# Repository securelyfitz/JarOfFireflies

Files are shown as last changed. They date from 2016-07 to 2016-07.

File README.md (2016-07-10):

# Jar of Fireflies
ATtiny-based Jar of Fireflies soldering project with inspiration and reuse from jason webb's https://github.com/jasonwebb/Jar-of-Fireflies

## Hardware Description
This project is intended to be a simple soldering project based on the ATTiny using only a handful of through-hole components. It uses 3 I/O pins to drive 6 charlieplexed LEDs, and an additional 2 I/O pins to control a capacitive sensor.

I originally intended to have the jar's metal ring be touch sensitive alone. However, for cap sensing to work, you need to be grounded, and a PCB inside a glass jar isn't exactly grounded. To account for that, there are several exposed ground pads just inside the ring - touch the ring and one of those pads, and the cap sensing should work.

## Bill of Materials:
* 3x 150 Ohm Resistor
* 2x 1K Ohm Resistor
* 1x 1M Ohm Resistor
* 1x ATTiny85 8-DIP
* 1x 20mm CR2032 holder and battery
* (optional) 1x SMT SPST-NO reset button

##Building
See the PDF for step by step images of building the pcb.

All of the components are labeled right on the board. Rev 1.0 of the board had a minor issue where R4 and R5 were swapped, if you have a Rev 1.0 board, it probably has a sticker correcting it.

You can optionally put the battery holder on the bottom of the board, to keep it out of reach of small hands. Just be sure to trim the pointy leads after soldering.

I used 30 gague wire and gullwing reverse-mount LEDs I had lying around. I soldered 2 LEDs in opposite polarity along each pair of wires. This mean I don't have to worry about the polarity when i solder it to the PCB. I did leave 6 pads for LEDs in case you want to do it the normal way.

##Software Description
This code is an Arduino sketch. I used the Sparkfun TinyAVR Programmer and follow the linked hookup guide to get it working: https://www.sparkfun.com/products/11801

The code for lighting the Charlieplexed LED's is cut and pasted from Jason Webb's project linked above. The code for sensing the capacitive buttons is based on Paul Stoffregen's updated CapacitiveSensor libarry: https://github.com/PaulStoffregen/CapacitiveSensor 

I rely heavily on global variables, and use the state and values to determine what to display on any given iteration. This allows me to responsively check the capsense button without dealing with interrupts.

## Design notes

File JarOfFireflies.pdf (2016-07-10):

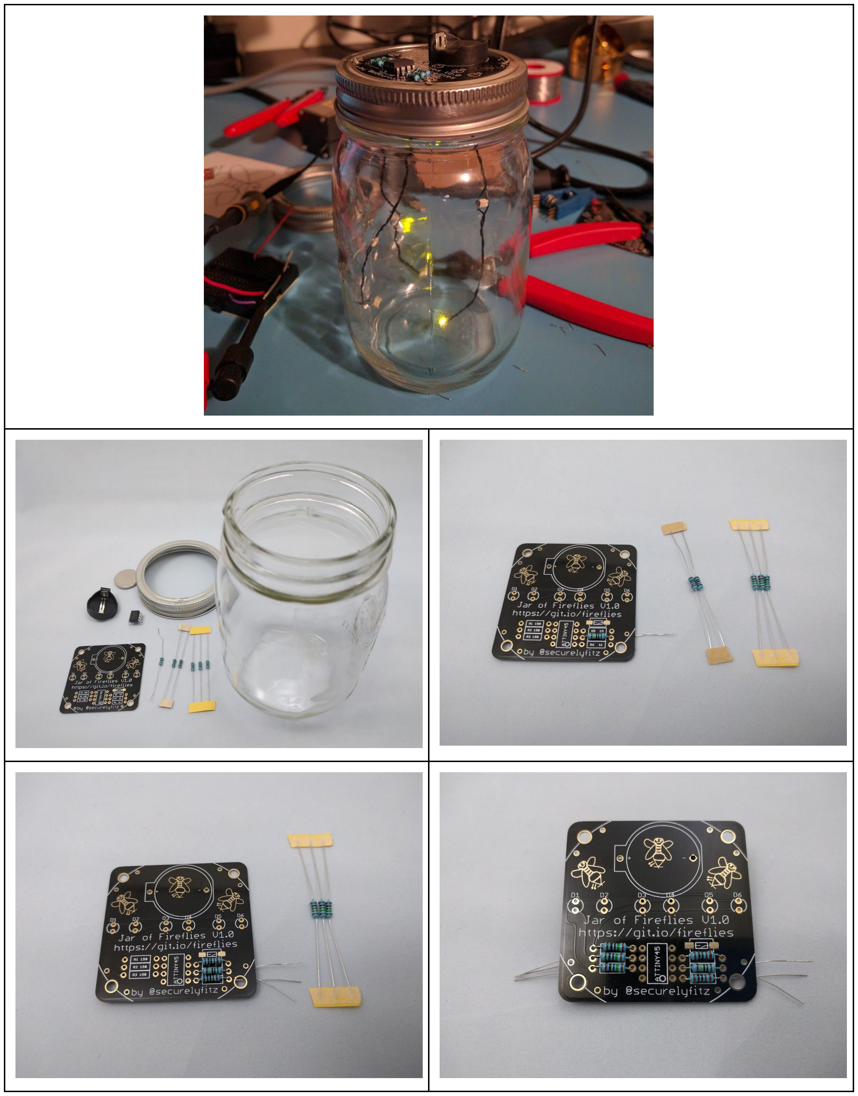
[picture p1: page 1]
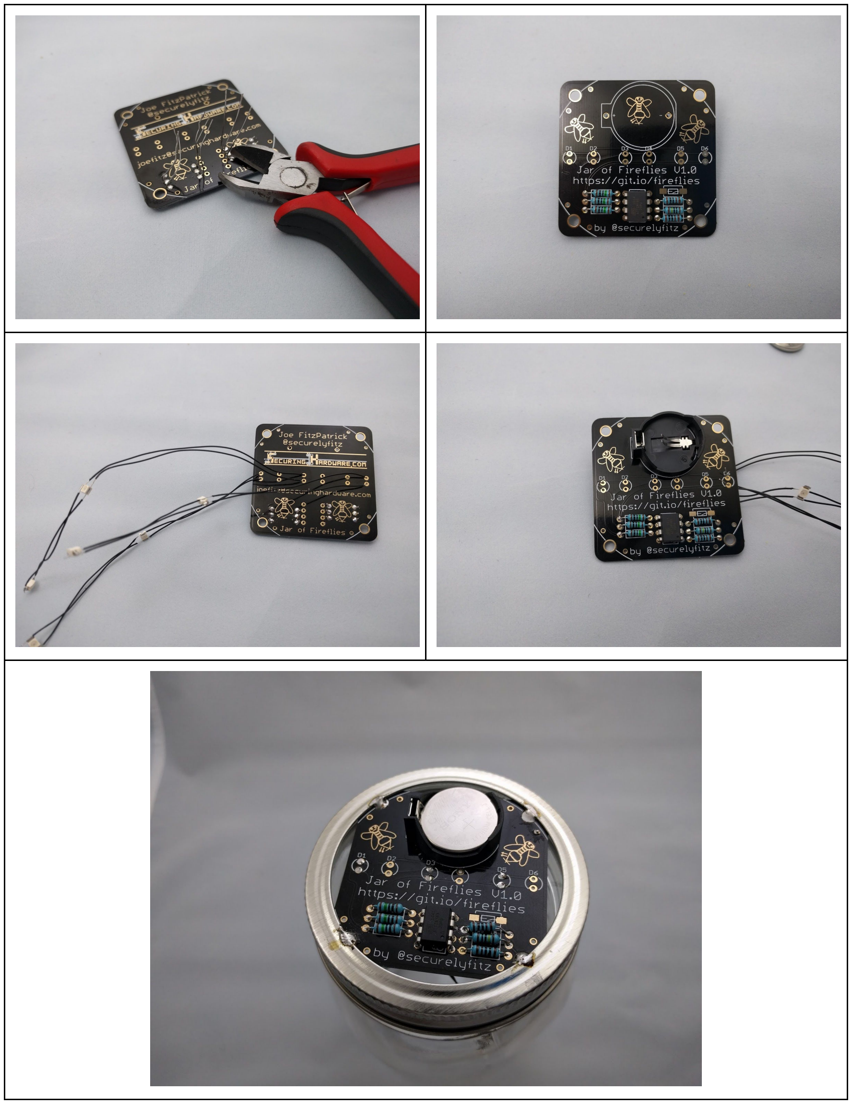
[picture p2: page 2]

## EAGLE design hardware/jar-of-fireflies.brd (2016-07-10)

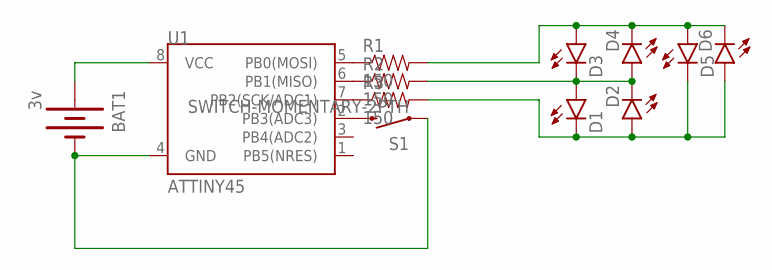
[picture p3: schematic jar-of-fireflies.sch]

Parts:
BAT1: 3v; BATTCOM_20MM_PTH
D1, D2, D3, D4, D5, D6: LED3MM
R1, R2, R3: 150; AXIAL-0.4
S1: SWITCH-MOMENTARY-2PTH; TACTILE-PTH
U1: ATTINY45; DIP08

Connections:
GND: BAT1.2 (-), S1.1, U1.4 (GND)
unnamed: R1.P$1 (1), U1.5 (PB0(MOSI))
unnamed: R2.P$1 (1), U1.6 (PB1(MISO))
unnamed: R3.P$1 (1), U1.7 (PB2(SCK/ADC1))
unnamed: S1.3 (2), U1.2 (PB3(ADC3))
unnamed: D3.A, D4.K (C), D5.A, D6.K (C), R1.P$2 (2)
unnamed: D1.K (C), D2.A, D5.K (C), D6.A, R3.P$2 (2)
unnamed: D1.A, D2.K (C), D3.K (C), D4.A, R2.P$2 (2)
VCC: BAT1.1 (+), U1.8 (VCC)

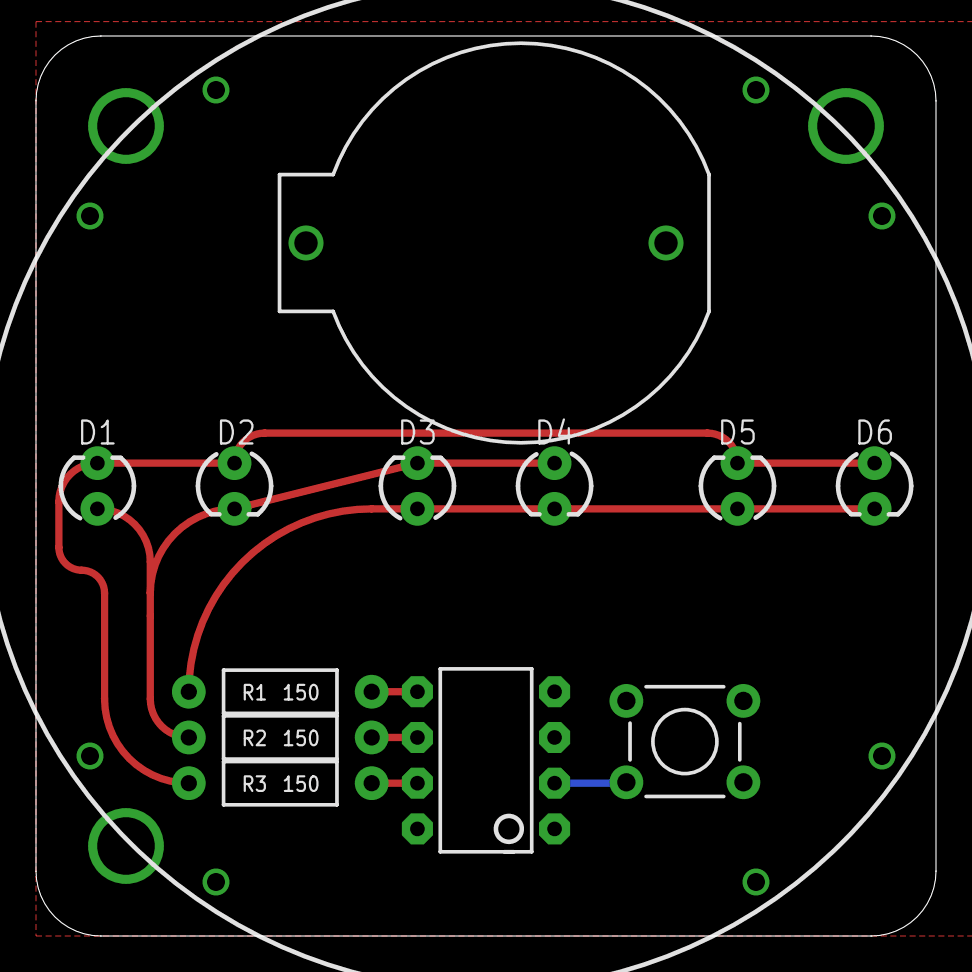
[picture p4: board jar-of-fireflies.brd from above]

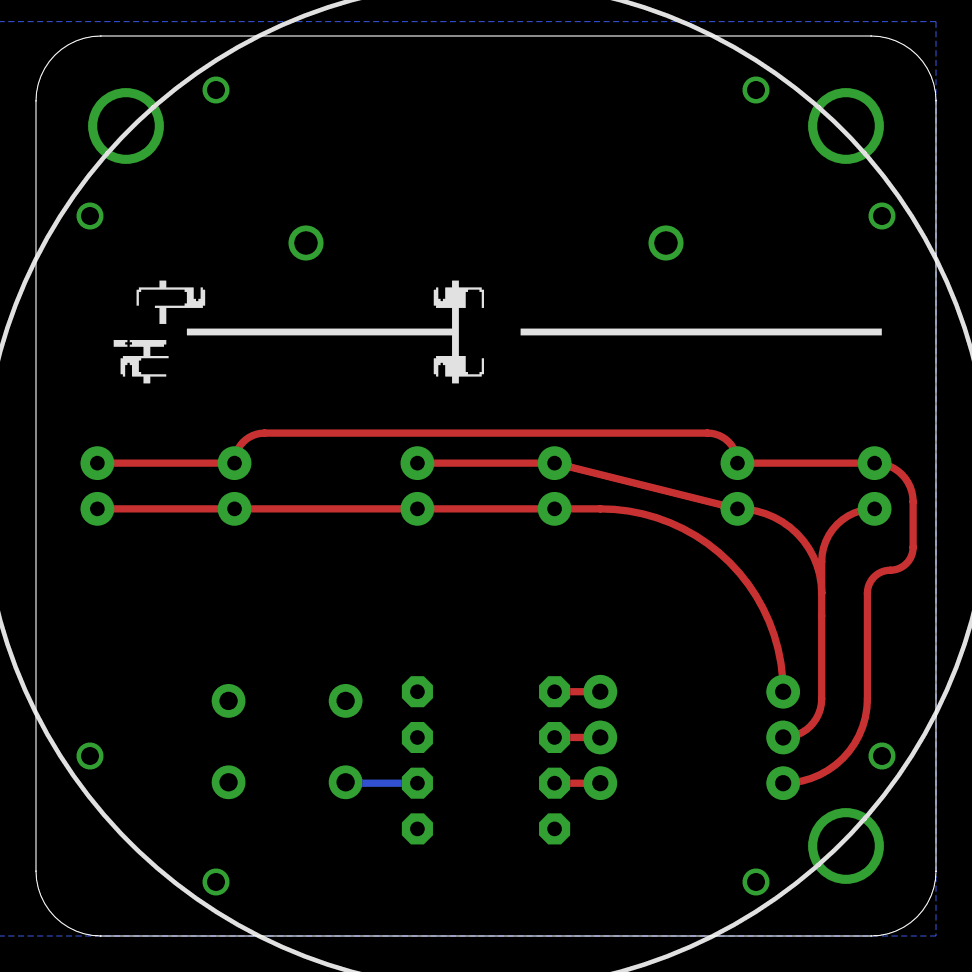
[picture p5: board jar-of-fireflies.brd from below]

Board: 2 copper layers, 50.0 x 50.0 mm, 18 parts (3 on the bottom side), 9 nets.

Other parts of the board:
U$1: SECURINGHARDWAREDOTCOM
U$2, U$3, U$4, U$5, U$6: FIREFLY

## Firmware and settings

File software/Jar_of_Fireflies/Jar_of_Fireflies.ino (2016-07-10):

/*
Yet Another ATTiny-based Jar of Fireflies
Joe FitzPatrick, @securelyfitz, joefitz@securinghardware.com

Software, hardware, and build notes at https://git.io/fireflies

Arduino sketch for ATTiny45+ based jar of fireflies. 6 charlieplexed LEDs plus a capacitive button
Based very heavily on Jason Webb's jar of fireflies:

todos:
--be more consistent with globals vs. passed values
--clean up state change code
--fix 1 vs 2 led option
--switch power modes when in state 0 to prolong standby battery life https://learn.sparkfun.com/tutorials/h2ohno/low-power-attiny
--turn off ADC to save power

Jason Webb - zen.webb@gmail.com
Project wiki: http://jason-webb.info/wiki/index.php?title=Jar_of_Fireflies
Github repo: https://github.com/jasonwebb/Jar-of-Fireflies
*/

#define F_CPU 1000000

#include <CapacitiveSensor.h>

// Pin assignments
const byte pinA = 0;
const byte pinB = 1;
const byte pinC = 2;

//i'm lazy so i use a ton of global variables to track state
int currled=0;
//int numleds=1;
int count=0;
int currstate=0;
int startmillis=0;
int currmillis=0;
int flashmillis=0;
int delaymillis=0;
bool pressed=false;

CapacitiveSensor   cs_3_4 = CapacitiveSensor(3,4);        // 10M resistor between pins 3 & 4, pin 4 is sensor pin, add a wire and or foil if desired

void setup() {
  // Flush any stray current from the ports
  turnOffAll();
  // flash each LED to show they work and so we know we just put in a good battery
  for(int j=0; j<6; j++) {
    turnOn(j);
    delay(250);
  }
/*  numleds=2;
  for(int j=0; j<6; j++) {
    turnOn(j);
    delay(250);
  }
  numleds=1;
*/
  turnOffAll();
}

void loop() {    
  //debounce capacitive sensor
  if(pressed){
    if((cs_3_4.capacitiveSensor(1)<10)){
      pressed=false;
    }
  }else{
    if(cs_3_4.capacitiveSensor(1)>50){
      pressed=true;
      state(currstate+1);
    }
  }

  //LED state is depentend on a combination of all those global variables, plus the elapsed time since entering that state:
  currmillis=millis()-startmillis;

  //do all the work. all this to just set an LED based on the elapsed milliseconds and current state.
  switch(currstate) {
    case 0:
      turnOffAll();
    break;
    case 1:  //one long flash
      multiflash(2,4096,4096,0,0);
    break;
    case 2: //flash quickly for a minute
      multiflash(120,250,750,0,0);
    break;
    case 3: //flash slow for 5 minutes with pause in between
      multiflash(60,2500,7500,500,2500);
    break;
    case 4: //flash random quick forever
      multiflash(0,250,750,0,0);
    break;
    case 5: //flash slow forever with pause inbetween
      multiflash(0,2500,7500,500,2500);
    break;
  }
}

//all this to maintain state between loops
void multiflash(int numflashes,int minflash,int maxflash,int mindelay,int maxdelay){
      //if our counter decrements, turn off (state 0)
      if ((count>=numflashes)and(numflashes!=0)){
        count=0;
        state(0);
      //if we've exceeded the lenth of time for the current flash, prepare for the next flash
      }else if(currmillis>flashmillis+delaymillis){
        startmillis=millis();  
        currled=random(0,5);
//        numleds=random(1,2);
        flashmillis=random(minflash,maxflash);
        delaymillis=random(mindelay,maxdelay);
        count++;
      //otherwise. flash a LED
      } else {
        timedflash(currled,flashmillis,currmillis);
      }
}

//resets a ton of global variables to enter a different state
void state(int nextstate){ 
        turnOffAll(); 
        currstate=nextstate;  
        currstate%=6;
        startmillis=millis();  
        flashmillis=0;
        delaymillis=0;
        currled=random(0,5);
//        numleds=random(1,2);
}


//this sets the right PWM value for the LED based on how long the tootal flash should be and how much time has elapsed
void timedflash(int led, int totalmillis, int elapsedmillis){
  //if we're past the end of the flash, then off
  if (elapsedmillis>totalmillis){
    turnOff(led);
  //if we're the first second, then fade in proportionally
  }else if (elapsedmillis<1024){
    analogOn(led,byte(elapsedmillis/4));
  //if we're in the last second, then fade out proportionally
  }else if (totalmillis-elapsedmillis<1024){
    analogOn(led,(totalmillis-elapsedmillis)/4);
  //otherwise, just stay lit
  }else{
    turnOn(led);
  }
}

//useful test function
void flash(int count){
  for(int i=0;i<=count;i++){
    turnOn(1);
    delay(500);
    turnOff(1);
    delay(500);
  }
}

// Turn on a single LED to full brightness
void turnOn(byte led) {
  analogOn(led, 255);
}

// Turn off an LED completely
void turnOff(byte led) {
  analogOn(led, 0);
}

//turns off all LEDs. Should be fixed to use the pin assignments instead of pin numbers directly
void turnOffAll() {
  for(int i=0; i<=2; i++) {
    pinMode(i, OUTPUT);
    digitalWrite(i, LOW);
  }
}

//this chooses between illuminating 1 or 2 charlieplexed LEDs
//not working properly right now
/*
void analogOn12(byte led, byte value) {
  if (numleds==1){
    analogOn(led,value);
  }else{
    analogOn2(led,value);
  }
}


// Write an analog value to 2 LEDs. Thanks to charlieplexing, we can some pairs of LEDs on at once.
//not working properly yet
void analogOn2(byte led, byte value) {
  switch(led) {
    case 0:
      pinMode(pinA, OUTPUT);
      pinMode(pinB, OUTPUT);
      pinMode(pinC, OUTPUT);
      
      digitalWrite(pinA, LOW);
      digitalWrite(pinC, LOW);
      analogWrite(pinB, value);
      break;
    case 1:
      pinMode(pinA, OUTPUT);
      pinMode(pinB, OUTPUT);
      pinMode(pinC, OUTPUT);
      
      digitalWrite(pinB, LOW);
      digitalWrite(pinC, LOW);
      analogWrite(pinA, value);
      break;
    case 2:
      pinMode(pinA, OUTPUT);
      pinMode(pinB, OUTPUT);
      pinMode(pinC, OUTPUT);
      
      digitalWrite(pinC, HIGH);
      digitalWrite(pinA, HIGH);
      analogWrite(pinB, 255-value);
      break;
    case 3:
      pinMode(pinA, OUTPUT);
      pinMode(pinB, OUTPUT);
      pinMode(pinC, OUTPUT);
      
      digitalWrite(pinC, LOW);
      digitalWrite(pinA, LOW);
      analogWrite(pinB, value);
      break;
    case 4:
      pinMode(pinA, OUTPUT);
      pinMode(pinB, OUTPUT);
      pinMode(pinC, OUTPUT);
      
      digitalWrite(pinC, HIGH);
      digitalWrite(pinB, HIGH);
      analogWrite(pinA, 255-value);
      break;
    case 5:
      pinMode(pinA, OUTPUT);
      pinMode(pinB, OUTPUT);
      pinMode(pinC, OUTPUT);
      
      digitalWrite(pinC, LOW);
      digitalWrite(pinB, LOW);
      analogWrite(pinA, value);
      break;
  }
}
*/
// Write an analog value to an LED - just one LED
void analogOn(byte led, byte value) {
  switch(led) {
    case 0:
      pinMode(pinA, OUTPUT);
      pinMode(pinB, OUTPUT);
      pinMode(pinC, INPUT);
      
      digitalWrite(pinA, LOW);
      analogWrite(pinB, value);
      break;
    case 1:
      pinMode(pinA, OUTPUT);
      pinMode(pinB, OUTPUT);
      pinMode(pinC, INPUT);
      
      digitalWrite(pinB, LOW);
      analogWrite(pinA, value);
      break;
    case 2:
      pinMode(pinA, INPUT);
      pinMode(pinB, OUTPUT);
      pinMode(pinC, OUTPUT);
      
      digitalWrite(pinC, HIGH);
      analogWrite(pinB, 255-value);
      break;
    case 3:
      pinMode(pinA, INPUT);
      pinMode(pinB, OUTPUT);
      pinMode(pinC, OUTPUT);
      
      digitalWrite(pinC, LOW);
      analogWrite(pinB, value);
      break;
    case 4:
      pinMode(pinA, OUTPUT);
      pinMode(pinB, INPUT);
      pinMode(pinC, OUTPUT);
      
      digitalWrite(pinC, HIGH);
      analogWrite(pinA, 255-value);
      break;
    case 5:
      pinMode(pinA, OUTPUT);
      pinMode(pinB, INPUT);
      pinMode(pinC, OUTPUT);
      
      digitalWrite(pinC, LOW);
      analogWrite(pinA, value);
      break;
  }
}

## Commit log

2016-05-31 first revision of a attiny-based jar of fireflies board that fits in a narrow-mouth mason jar lid.
    [jar-of-fireflies.brd, jar-of-fireflies.sch]
2016-05-31 Rev 1.1: fixed swapped 1M and 1K resistors, incremented version number.
    [jar-of-fireflies.brd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]
2016-06-05 moved hardware files into subdirectory
    [jar-of-fireflies.brd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]
2016-06-05 adding arduino sketch
2016-07-10 up to rev 1.2. Gave up on touch sense, replaced with through-hole switch, fewer components!
    [jar-of-fireflies.brd, jar-of-fireflies.sch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]

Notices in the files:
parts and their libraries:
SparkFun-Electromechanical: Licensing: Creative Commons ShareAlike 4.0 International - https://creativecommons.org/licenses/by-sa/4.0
